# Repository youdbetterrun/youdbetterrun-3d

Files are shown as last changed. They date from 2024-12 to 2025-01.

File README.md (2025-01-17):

# You'd Better Run!

This project lets you know if you can walk leisurely to catch the bus, or if you'd better run.

This is a screen that hangs on the wall by the door to at a glance see how much time you have to get to the bus stop.

Image of the completed project hanging on the wall

This repository holds the 3D models and assembly instructions.
There are separate repositories for the PCB and firmware models.
- [Firmware](https://github.com/youdbetterrun/youdbetterrun-firmware): The code that runs on the microcontroller.
- [PCB](https://github.com/youdbetterrun/youdbetterrun-pcb): The design files for the printed circuit board.

[Blog post about this project.](https://blog.marcelrobitaille.me/youdbetterrun/)

## Bill Of Materials

| Item | Quantity | Source |
| --- | --- | --- |
| Picture Frame | 1 | https://www.ikea.com/ca/en/p/roedalm-frame-oak-effect-10566390/ (It should be easy to adapt the 3D printing files for other sizes) |
| e-paper screen | 1 | [GoodDisplay 5.83" GDEQ0583T31](https://www.good-display.com/product/444.html) |
| Spacer | 1 | 3D printed |
| Mounting Plate | 1 | 3D printed |
| PCB | 1 | [sister repository](https://github.com/youdbetterrun/youdbetterrun-pcb) |
| M2x3mm heat set insert | 3 | https://cnckitchen.store/products/heat-set-insert-m2-x-3-100-pieces |
| M2x6mm BHCS | 3 | Hardware store |
| M3x6mm FHCS | 4 | Hardware store |
| M3 locking nut | 4 | Hardware store |

## Assembly Instructions

The image below shows the exploded view of the assembly.

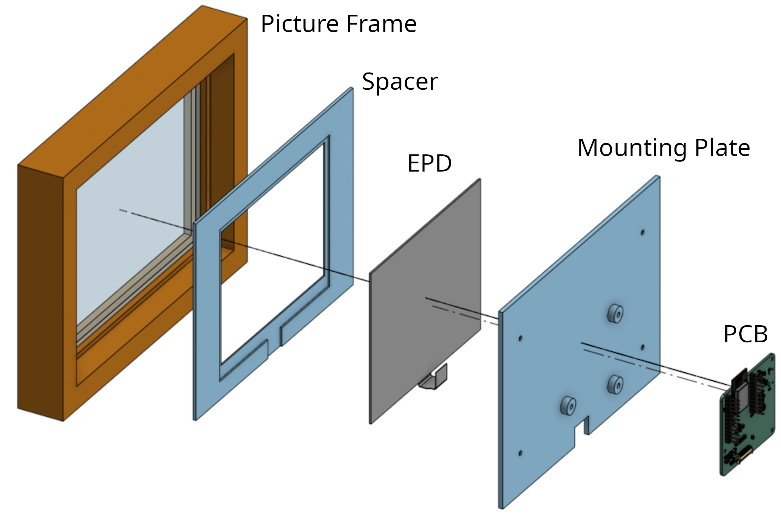
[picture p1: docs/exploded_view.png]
Exploded view


1. 3D print everything in the `./stl/` folder. I used white PLA. No supports necessary.
1. Add the 3 heat set inserts to the 3D-printed mounting plate.
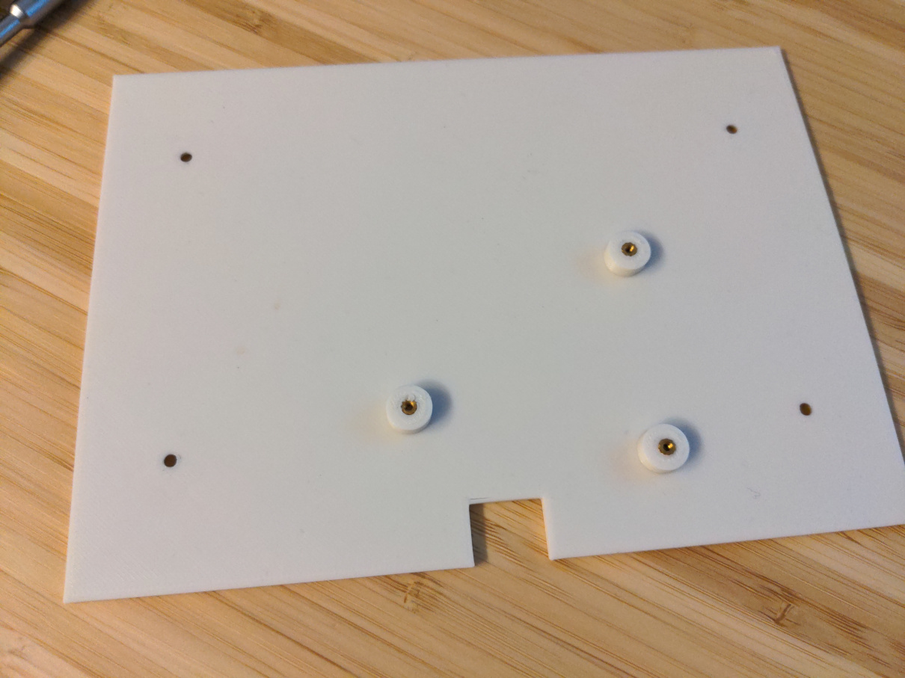
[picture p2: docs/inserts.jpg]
    
1. Leave the glass in the picture frame, but take out the back panel and the paper.
1. Add the spacer into the picture frame, then add the e-paper screen behind it.
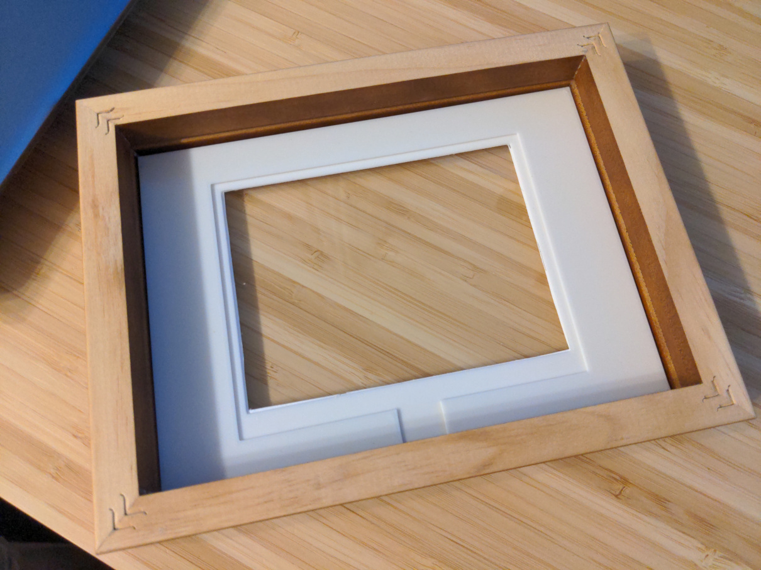
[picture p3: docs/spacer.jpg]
    
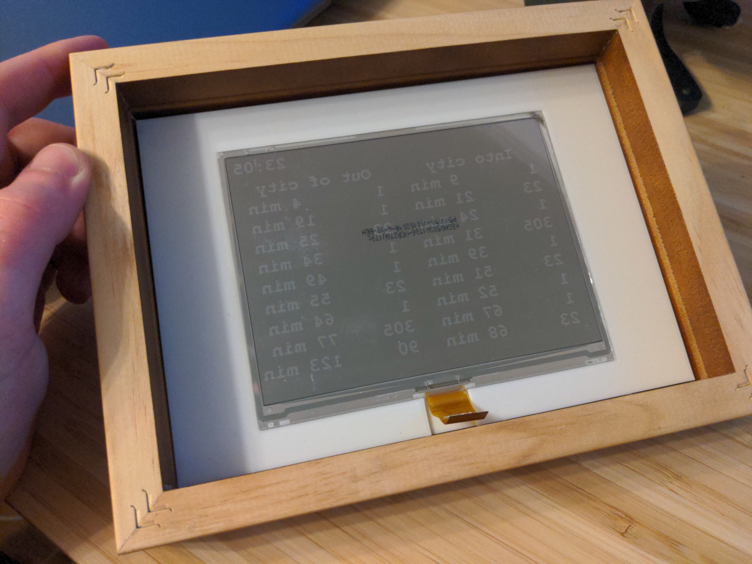
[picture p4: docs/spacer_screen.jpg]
    
1. Screw the PCB onto the mounting plate using the 3 BHCS.
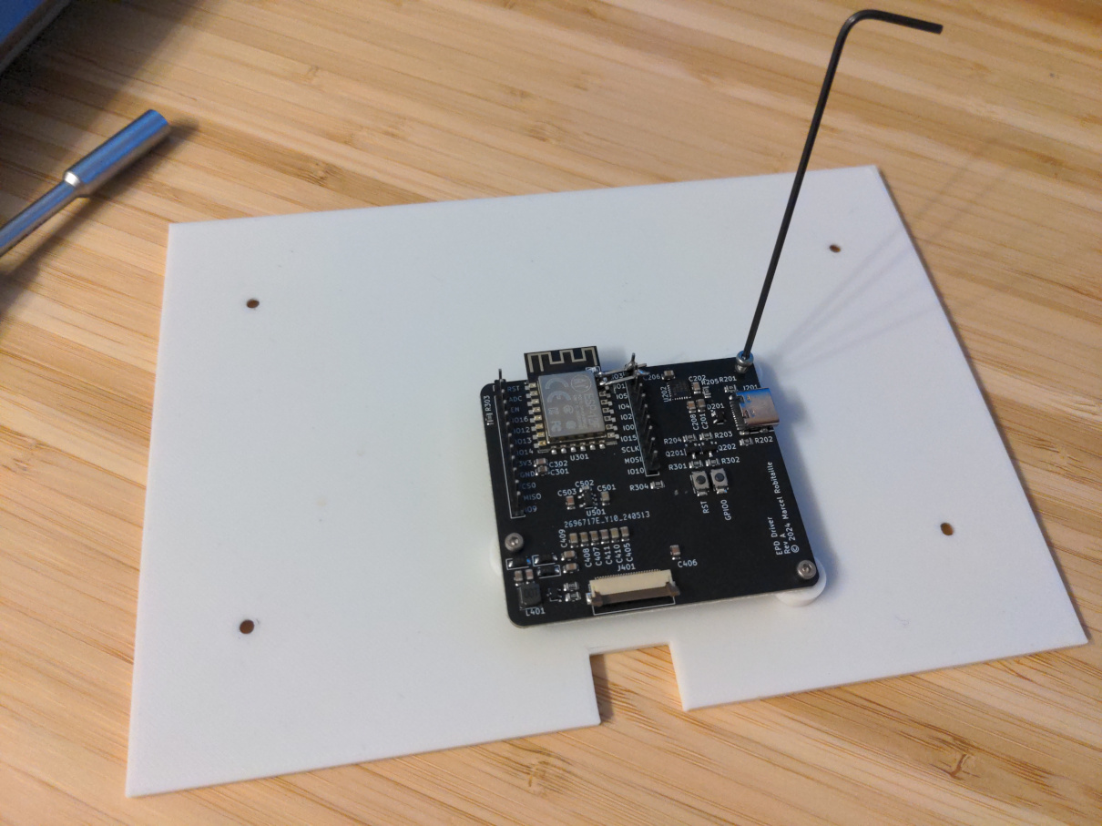
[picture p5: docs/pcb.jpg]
    
1. Take the clips out of the picture frame's original backing. Connect them to the 3D-printed mounting plate by inserting the FHCS from the other side and using the locking nuts.
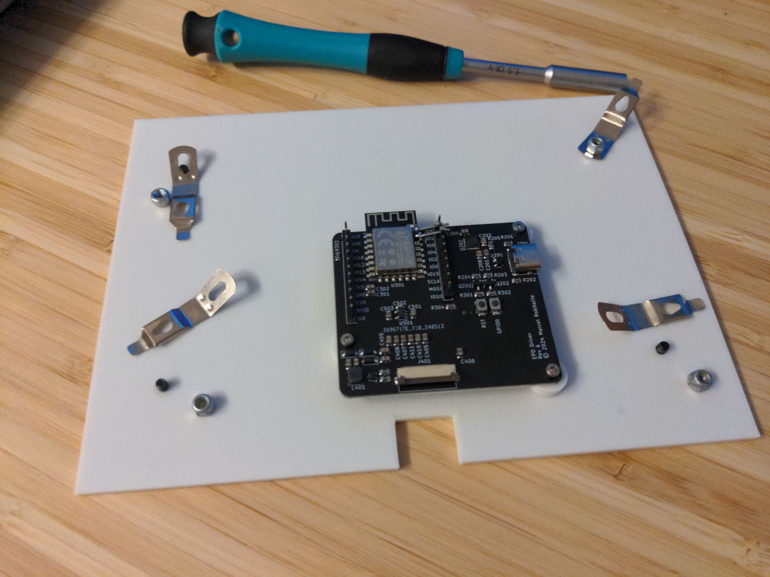
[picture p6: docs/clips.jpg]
    
1. Put the mounting plate into the picture frame. Slide the hooks into the walls of the picture frame, securing everything inside.
1. Plug in FFC cable. Make sure the clip is up, slide in the cable, then snap the clip down.
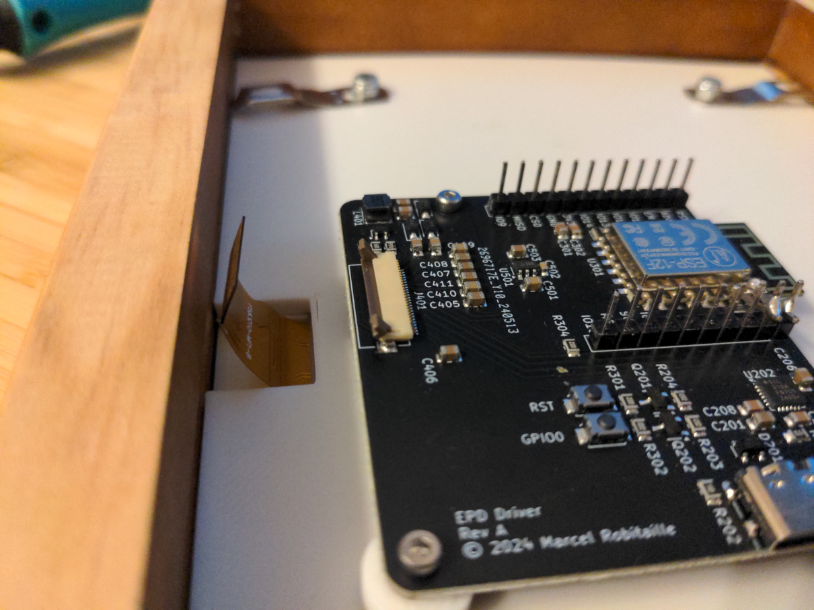
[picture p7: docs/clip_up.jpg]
    
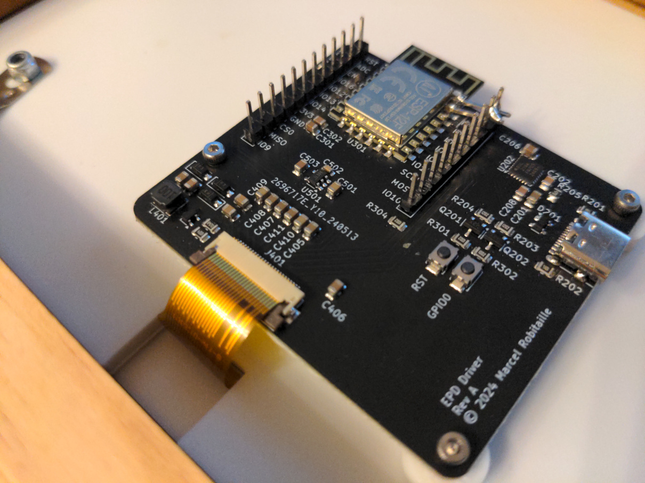
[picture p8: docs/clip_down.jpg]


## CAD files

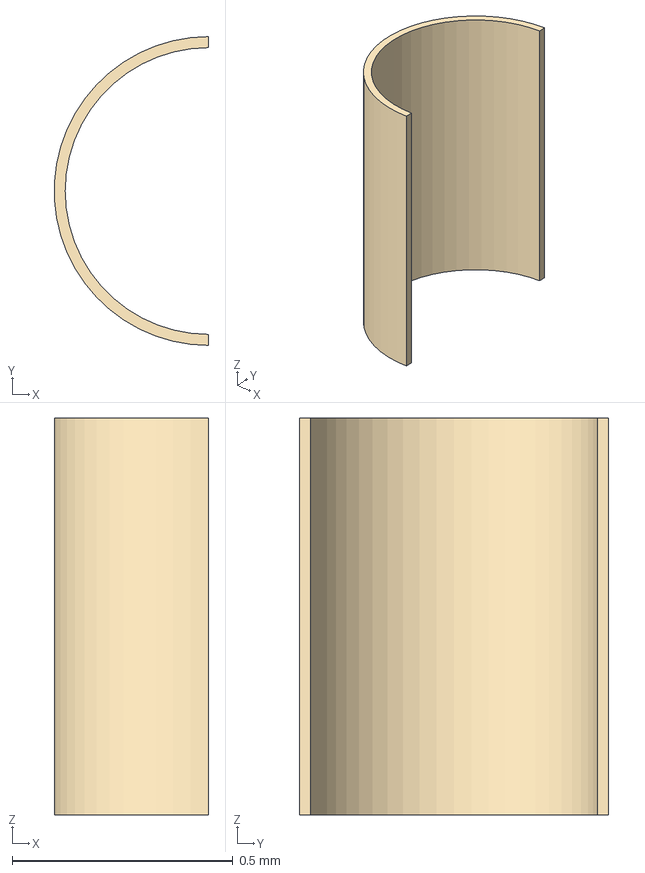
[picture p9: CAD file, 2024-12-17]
step/Main Assembly - ESP_12E001_cp (15).step
0.349 x 0.7 x 0.9 mm

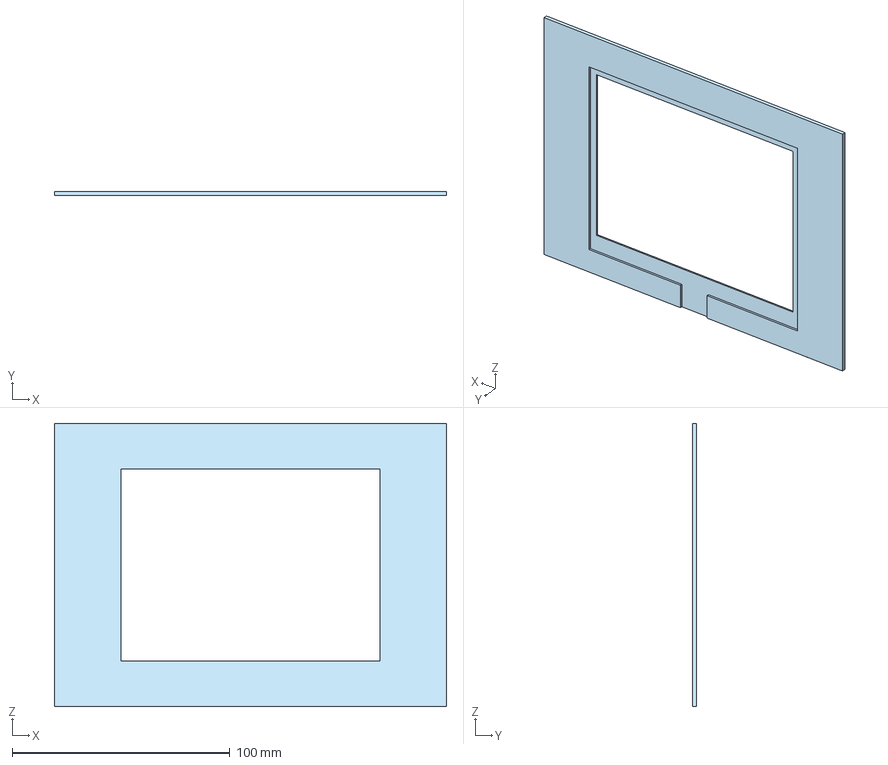
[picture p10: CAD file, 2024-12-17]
step/Main Assembly - Spacer.step
180.0 x 1.93 x 130.0 mm

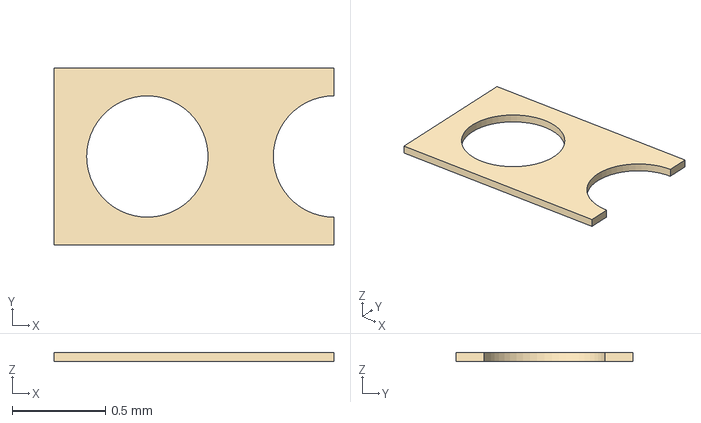
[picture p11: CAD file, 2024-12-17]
step/Main Assembly - ESP_12E001_cp (33).step
1.50 x 0.95 x 0.05 mm

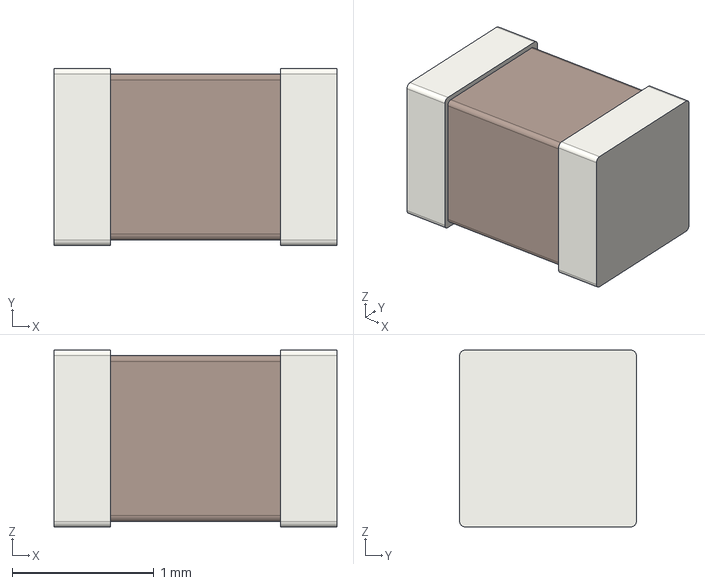
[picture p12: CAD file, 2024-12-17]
step/Main Assembly - C_0805_2012Metric (15).step
2.00 x 1.25 x 1.25 mm

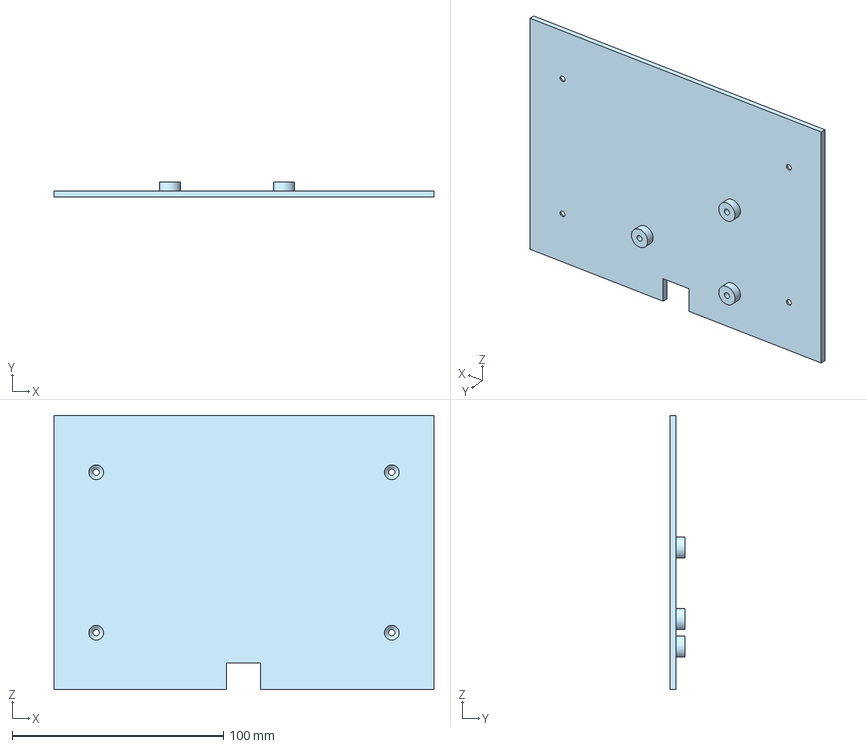
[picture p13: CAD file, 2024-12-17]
step/Main Assembly - Mounting Plate.step
180.0 x 7.14 x 130.0 mm

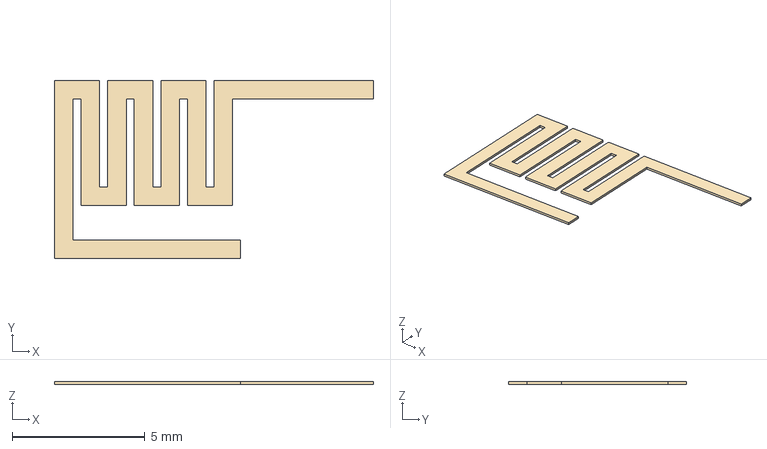
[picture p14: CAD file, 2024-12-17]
step/Main Assembly - ESP_12E001_cp (11).step
12.0 x 6.70 x 0.1 mm

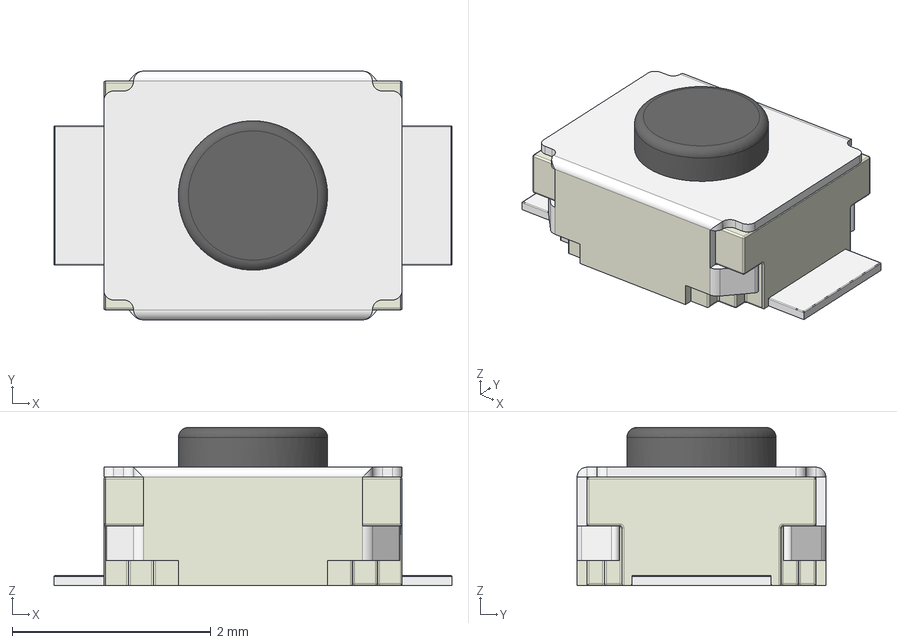
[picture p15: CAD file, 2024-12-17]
step/Main Assembly - SW_SPST_B3U-1000P.step
4.00 x 2.50 x 1.59 mm

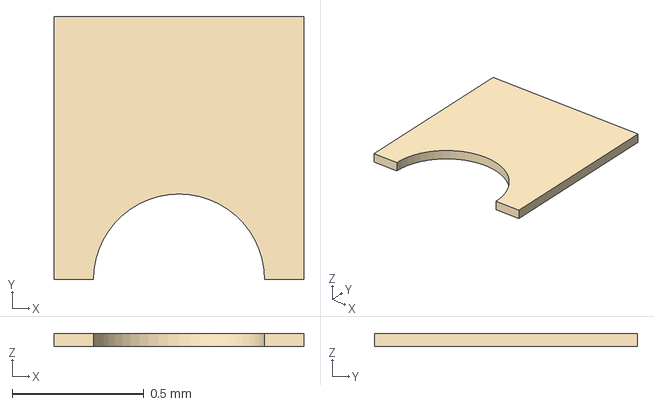
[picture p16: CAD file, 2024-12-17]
step/Main Assembly - ESP_12E001_cp (39).step
0.95 x 1.00 x 0.05 mm

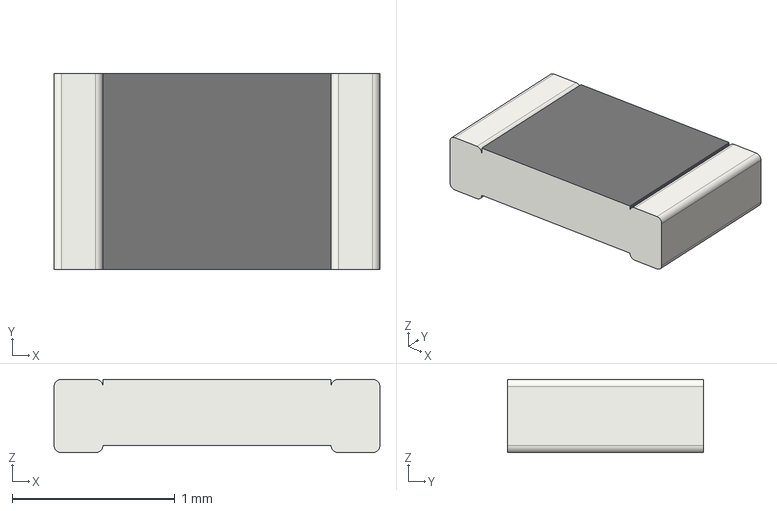
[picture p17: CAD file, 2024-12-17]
step/Main Assembly - R_0805_2012Metric.step
2.00 x 1.20 x 0.45 mm

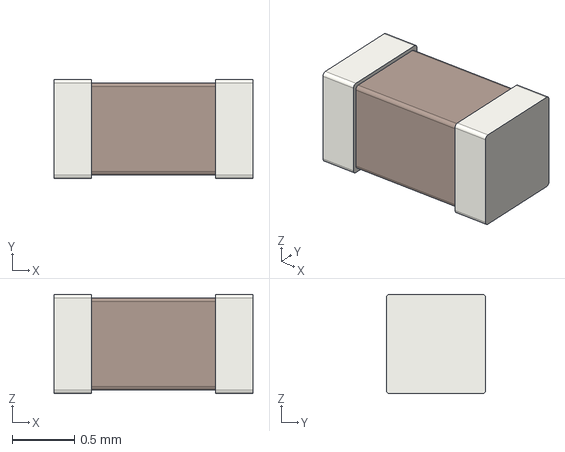
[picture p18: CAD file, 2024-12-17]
step/Main Assembly - C_0603_1608Metric.step
1.60 x 0.8 x 0.8 mm

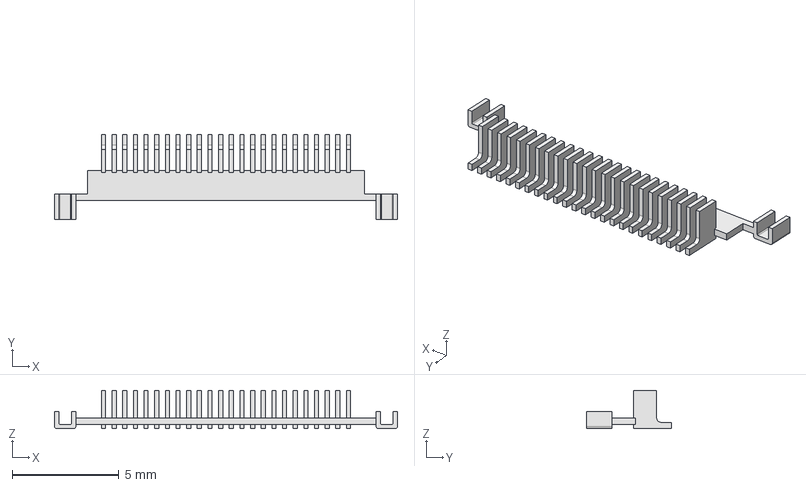
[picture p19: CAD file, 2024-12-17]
step/Main Assembly - Hirose_FH12_xxS_0_5SH_Parametric_v0_1.step
16.1 x 4.00 x 1.80 mm

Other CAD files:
step/Main Assembly - ESP_12E001_cp (14).step
step/Main Assembly - ESP_12E001_cp (46).step
step/Main Assembly - C_0805_2012Metric (17).step
step/Main Assembly - ESP_12E001_cp (18).step
step/Main Assembly - C_0805_2012Metric (12).step
step/Main Assembly - C_0805_2012Metric.step
step/Main Assembly - ESP_12E001_cp (40).step
step/Main Assembly - C_0805_2012Metric (1).step
step/Main Assembly - C_0805_2012Metric (10).step
step/Main Assembly - C_0805_2012Metric (11).step
step/Main Assembly - C_0805_2012Metric (13).step
step/Main Assembly - C_0805_2012Metric (14).step
step/Main Assembly - C_0805_2012Metric (16).step
step/Main Assembly - C_0805_2012Metric (18).step
step/Main Assembly - C_0805_2012Metric (2).step
step/Main Assembly - C_0805_2012Metric (3).step
step/Main Assembly - C_0805_2012Metric (4).step
step/Main Assembly - C_0805_2012Metric (5).step
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

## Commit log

2024-12-17 Add epd to BOM
2024-12-17 Orient STLs for printing
    [YoudBetterRun 3D Prints - Mounting Plate.stl, YoudBetterRun 3D Prints - Spacer.stl]
2025-01-17 Add more pictures of the assembly
